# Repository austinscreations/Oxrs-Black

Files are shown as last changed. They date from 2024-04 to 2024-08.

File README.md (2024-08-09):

# Oxrs-Black
a custom rack controller that is based of the rack32 but includes some upgrades and major changes

With the latest update on 2024-08-09
- known part qty missing for the optoisolators - these are needed for KNX function. 

you can leave them off or preorder the part before PCBa from JLC
- https://jlcpcb.com/partdetail/avago_broadcom-ACPL_M61L500E/C44908

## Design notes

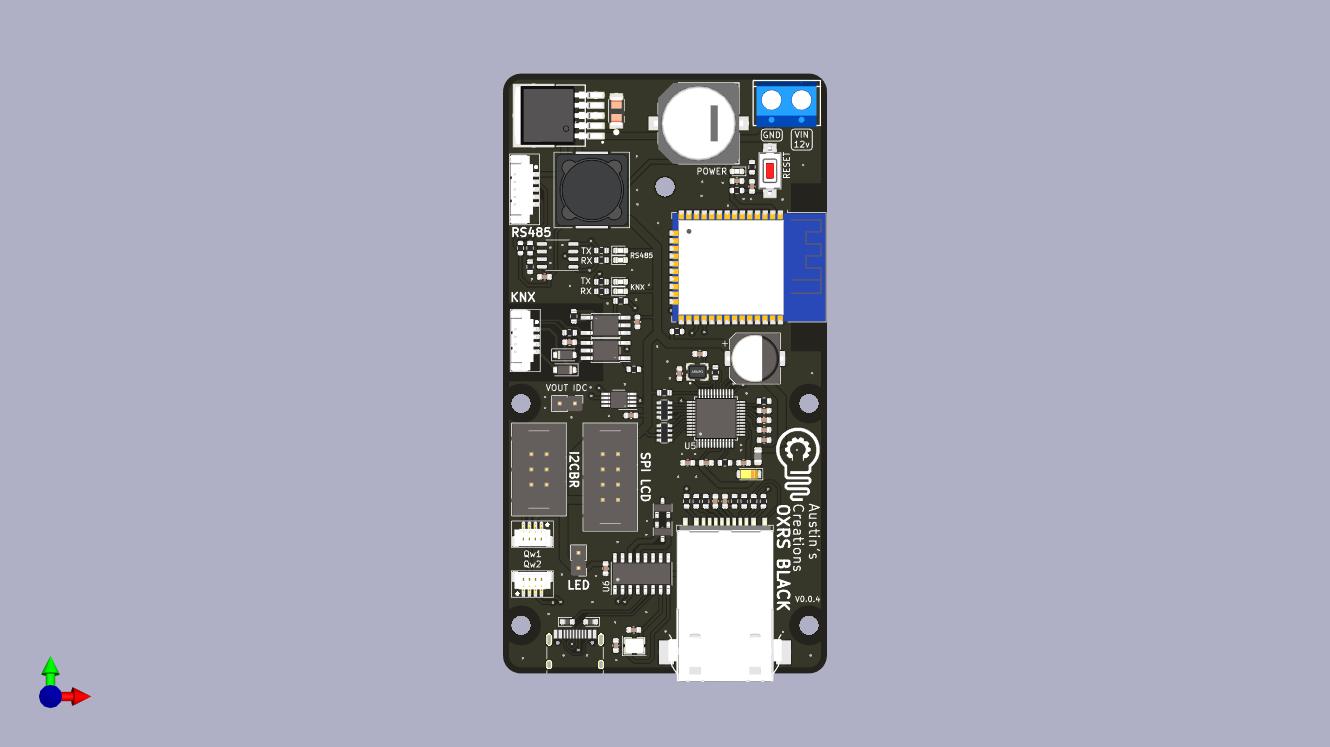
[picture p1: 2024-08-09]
rev 4/oxrs black 004 front.jpg

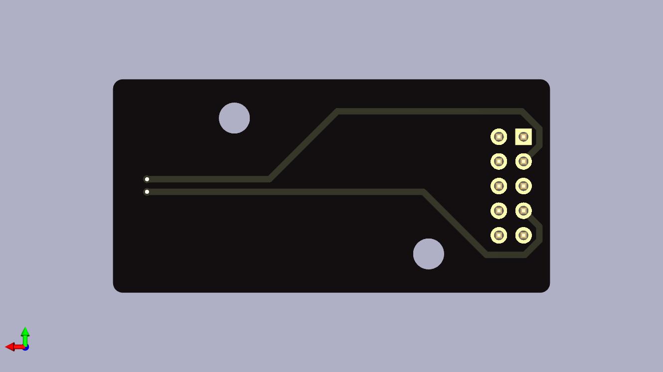
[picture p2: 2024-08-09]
knx adapter/knx adapter bottom.jpg

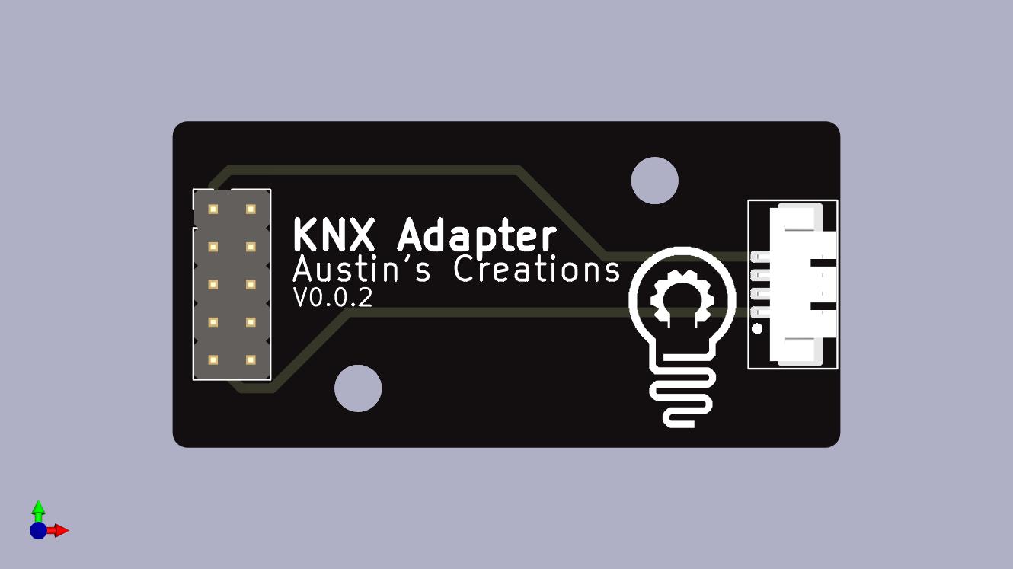
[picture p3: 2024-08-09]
knx adapter/knx adapter top.jpg

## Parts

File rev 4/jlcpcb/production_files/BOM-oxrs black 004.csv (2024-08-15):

Comment | Designator | Footprint | LCSC
PGB1010603NR | D7,D8 | D_0603_1608Metric | C10677
10uF 6.3V A TANT | C12 | CP_EIA-3216-18_Kemet-A | C127946
CH340G | U6 | SOIC-16_3.9x9.9mm_P1.27mm | C14267
qwiic_vertical | Qw1,Qw2 | qwiic vertical | C145961
100nF | C10,C15,C17,C18,C21,C3,C4,C5,C6 | C_0603_1608Metric | C14663
1uF | C9 | C_0603_1608Metric | C15849
20pF | C22,C23,C7,C8 | C_0603_1608Metric | C1648
4.7uF | C16 | C_0603_1608Metric | C19666
10uF | C11 | C_0603_1608Metric | C19702
MMBT3904 | Q1,Q2 | SOT-23 | C20526
22nF | C20 | C_0603_1608Metric | C21122
1k | R2,R3,R4,R5,R6,R7,R8,R9 | R_0603_1608Metric | C21190
KNX | J7 | 4 pin jst 1.25 vertical | C225106
RS485 | J4 | 5 pin jst 1.25 vertical | C225107
120R | R12 | R_0603_1608Metric | C22787
10R | R23 | R_0603_1608Metric | C22859
red | D2,D4,D6 | LED_0603_1608Metric | C2286
1M | R13 | R_0603_1608Metric | C22935
470R | R24,R25 | R_0603_1608Metric | C23179
49.9R | R19,R20,R21,R22 | R_0603_1608Metric | C23185
10k | R1,R10,R11,R14,R15,R16,R17 | R_0603_1608Metric | C25804
25MHz_SMD_Crystal_Resonator | Y1 | 25MHz_SMD_Crystal_Resonator | C258949
USB_C_Receptacle_USB2.0 | J6 | USB_C_Receptacle_HRO_TYPE-C-31-M-12 | C2765186
10k | RN1,RN2 | R_Array_Convex_4x0603 | C29718
ESP32-WROOM-32E | U4 | ESP32-WROOM-32 | C3013935
12.4k | R18 | R_0603_1608Metric | C310267
W5500 | U5 | LQFP-48_7x7mm_P0.5mm | C32843
LM2596S-3V3 | PS1 | LM2596S | C347420
2pinblock | TB1 | 2pinblock | C395885
button | B1 | button | C410373
ACPL-M61L-500E | U2,U3 | SO-5_4.4x3.6mm_P1.27mm | C44908
Conn_01x02 | J1,J3 | PinHeader_1x02_P2.54mm_Vertical | C492401
220uF 35v | C2 | CP_Elec_8x6.2 | C5162357
HR961160C | RJ45_1 | HR961160C | C55683
10nF | C13,C14,C19 | C_0603_1608Metric | C57112
CONN_03X2SHROUD | IDC1 | IDC-Header_2x03_P2.54mm_Vertical | C601936
SPI-LCD | J2 | IDC-Header_2x04_P2.54mm_Vertical | C601937
SM4007 | D10,D9 | D_SOD-123F | C64898
MAX3485 | U1 | SOP-8_3.9x4.9mm_P1.27mm | C668204
yellow | D3,D5 | LED_0603_1608Metric | C72038
TCA4307 | IC1 | VSSOP-8_3.0x3.0mm_P0.65mm | C880333
Crystal_GND23 | Y2 | Crystal_SMD_3225-4Pin_3.2x2.5mm | C9002
33uH | L1 | 12x12x8 inductor | C9400
PMEG4050EP | D1 | PMEG3050EP | C96235
680uF 35v | C1 | large capacitor 12.5d 13.5h | C98216
1uH 250mA 0805 | L2 | L_0805_2012Metric | C98325

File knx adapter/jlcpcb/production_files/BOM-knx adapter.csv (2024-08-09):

Comment | Designator | Footprint | LCSC
Conn_02x05_Odd_Even | J1 | PinHeader_2x05_P2.54mm_Vertical | C115170
KNX | J2 | 4 pin jst 1.25 horizontal | C225113

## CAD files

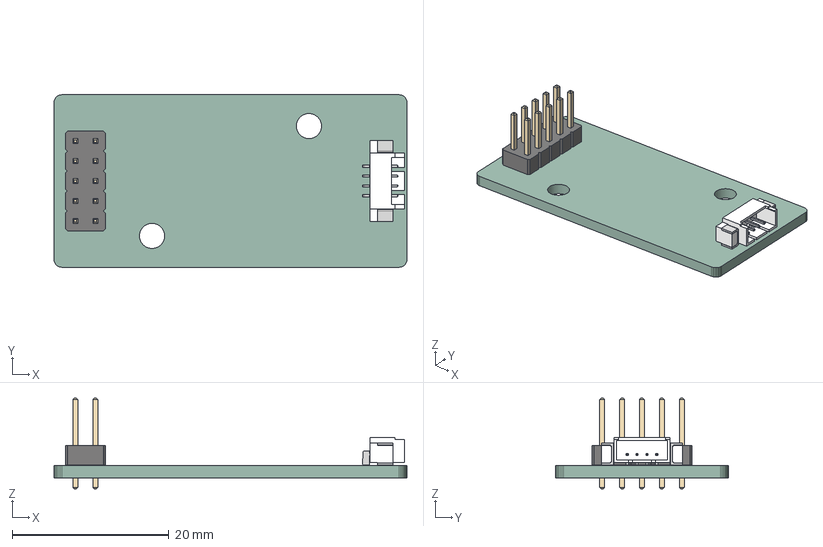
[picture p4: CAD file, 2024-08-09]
knx adapter/knx adapter.step
45.0 x 22.0 x 11.5 mm
knx adapter PCB

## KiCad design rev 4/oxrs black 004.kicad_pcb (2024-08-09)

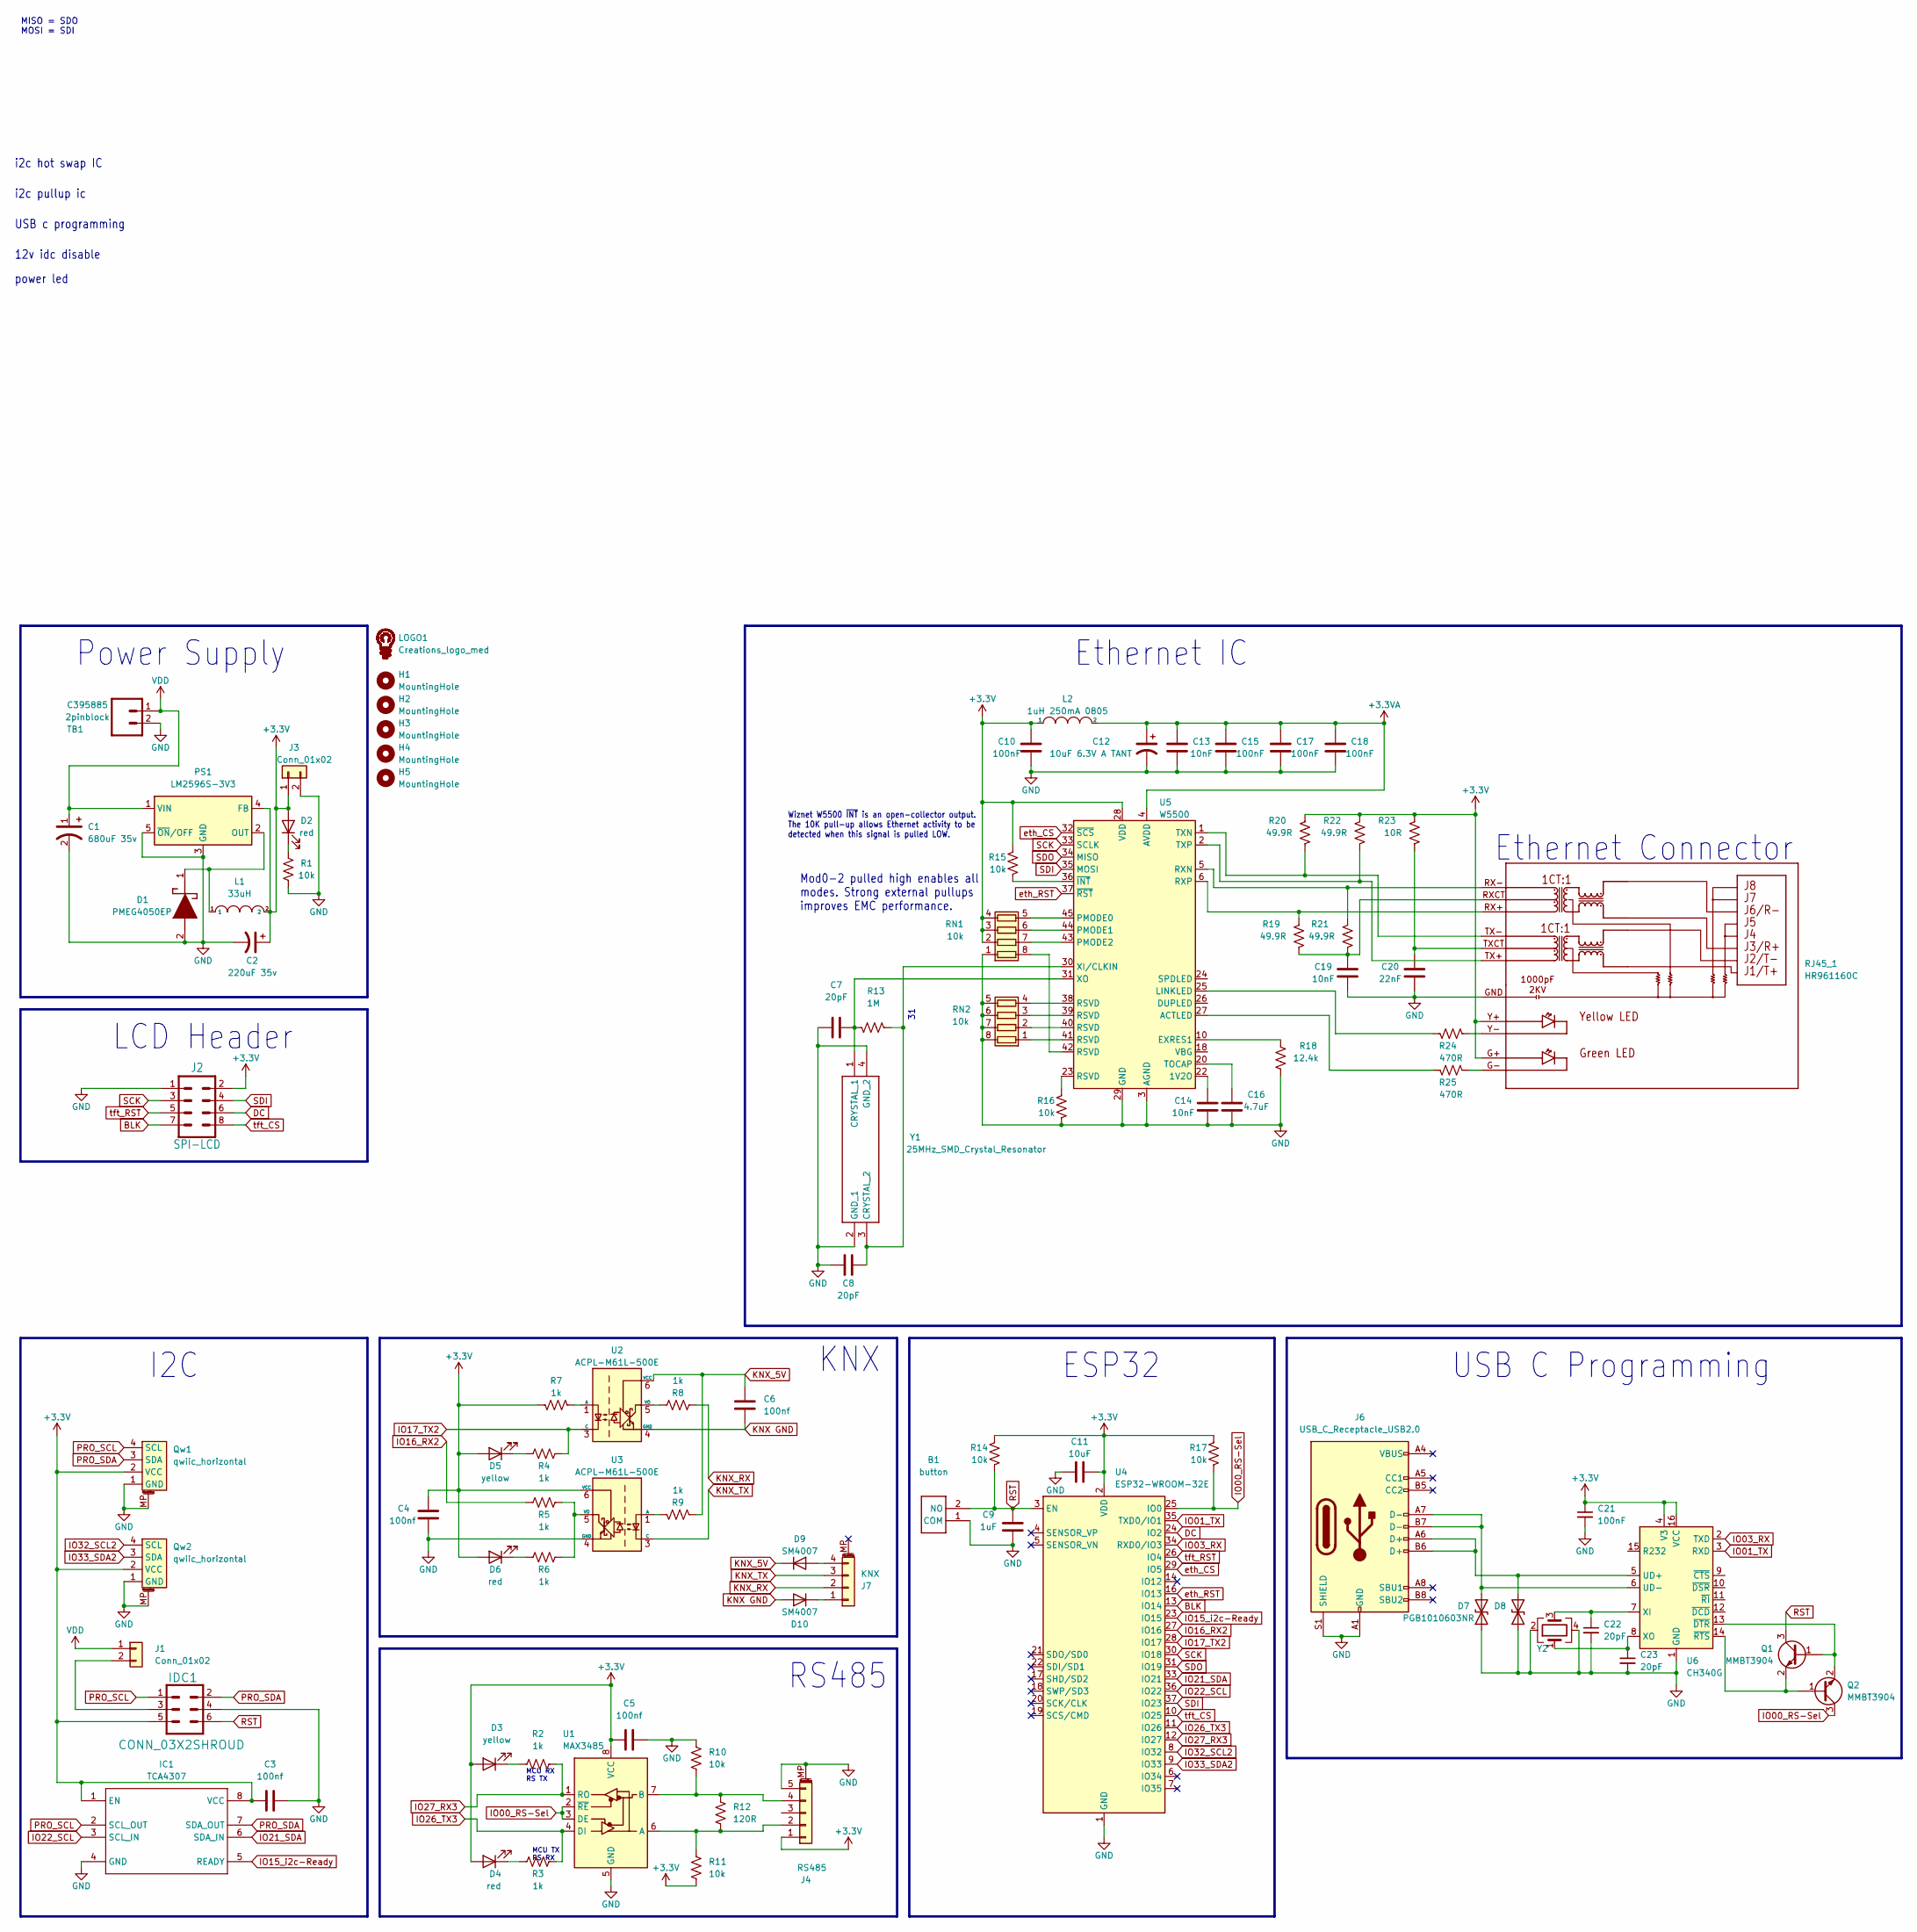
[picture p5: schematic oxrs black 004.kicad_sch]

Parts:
B1: button; LCSC C410373
C1: 680uF 35v; large capacitor 12.5d 13.5h; LCSC C98216
C2: 220uF 35v; CP_Elec_8x6.2; LCSC C5162357
C3, C4, C5, C6: 100nf; C_0603_1608Metric; LCSC C14663
C7, C8, C22, C23: 20pF; C_0603_1608Metric; LCSC C1648
C9: 1uF; C_0603_1608Metric; LCSC C15849
C10, C15, C17, C18, C21: 100nF; C_0603_1608Metric; LCSC C14663
C11: 10uF; C_0603_1608Metric; LCSC C19702
C12: 10uF 6.3V A TANT; CP_EIA-3216-18_Kemet-A; LCSC C127946
C13, C14, C19: 10nF; C_0603_1608Metric; LCSC C57112
C16: 4.7uF; C_0603_1608Metric; LCSC C19666
C20: 22nF; C_0603_1608Metric; LCSC C21122
D1: PMEG4050EP; PMEG3050EP; LCSC C96235
D2, D4, D6: red; LED_0603_1608Metric; LCSC C2286
D3, D5: yellow; LED_0603_1608Metric; LCSC C72038
D7, D8: PGB1010603NR; D_0603_1608Metric; LCSC C10677
D9, D10: SM4007; D_SOD-123F; LCSC C64898
H1, H2, H3, H4, H5: MountingHole; MountingHole_3.2mm_M3
IC1: TCA4307; VSSOP-8_3.0x3.0mm_P0.65mm; LCSC C880333
IDC1: CONN_03X2SHROUD; IDC-Header_2x03_P2.54mm_Vertical; LCSC C601936
J1, J3: Conn_01x02; PinHeader_1x02_P2.54mm_Vertical; LCSC C492401
J2: SPI-LCD; IDC-Header_2x04_P2.54mm_Vertical; LCSC C601937
J4: RS485; 5 pin jst 1.25 vertical; LCSC C225107
J6: USB_C_Receptacle_USB2.0; USB_C_Receptacle_HRO_TYPE-C-31-M-12; LCSC C2765186
J7: KNX; 4 pin jst 1.25 vertical; LCSC C225106
L1: 33uH; 12x12x8 inductor; LCSC C9400
L2: 1uH 250mA 0805; L_0805_2012Metric; LCSC C98325
LOGO1: Creations_logo_med; Creations logo med
PS1: LM2596S-3V3; LM2596S; LCSC C347420
Q1, Q2: MMBT3904; SOT-23; LCSC C20526
Qw1, Qw2: qwiic_horizontal; qwiic vertical; part # C145961; LCSC C145956
R1, R10, R11, R14, R15, R16, R17: 10k; R_0603_1608Metric; LCSC C25804
R2, R3, R4, R5, R6, R7, R8, R9: 1k; R_0603_1608Metric; LCSC C21190
R12: 120R; R_0603_1608Metric; LCSC C22787
R13: 1M; R_0603_1608Metric; LCSC C22935
R18: 12.4k; R_0603_1608Metric; LCSC C310267
R19, R20, R21, R22: 49.9R; R_0603_1608Metric; LCSC C23185
R23: 10R; R_0603_1608Metric; LCSC C22859
R24, R25: 470R; R_0603_1608Metric; LCSC C23179
RJ45_1: HR961160C; LCSC C55683
RN1, RN2: 10k; R_Array_Convex_4x0603; LCSC C29718
TB1: 2pinblock; LCSC C395885
U1: MAX3485; SOP-8_3.9x4.9mm_P1.27mm; part # C9943; LCSC C668204
U2, U3: ACPL-M61L-500E; SO-5_4.4x3.6mm_P1.27mm; LCSC C44908
U4: ESP32-WROOM-32E; ESP32-WROOM-32; LCSC C3013935
U5: W5500; LQFP-48_7x7mm_P0.5mm; LCSC C32843
U6: CH340G; SOIC-16_3.9x9.9mm_P1.27mm; LCSC C14267
Y1: 25MHz_SMD_Crystal_Resonator; LCSC C258949
Y2: Crystal_GND23; Crystal_SMD_3225-4Pin_3.2x2.5mm; LCSC C9002

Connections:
+3.3VA: C12.1, C13.2, C15.2, C17.2, C18.2, L2.2, U5.4 (AVDD), U5.8 (AVDD), U5.11 (AVDD), U5.15 (AVDD), U5.17 (AVDD), U5.21 (AVDD)
+3V3: C2.1, C3.2, C4.1, C5.2, C10.2, C11.2, C21.1, D2.2 (A), D3.2 (A), D4.2 (A), D5.2 (A), D6.2 (A), IC1.1 (EN), IC1.8 (VCC), IDC1.5, J2.2, J3.1, J4.1, L1.2, L2.1, PS1.4 (FB), Qw1.2 (VCC), Qw2.2 (VCC), R7.1, R11.1, R14.2, R15.2, R17.2, R20.2, R22.2, R23.2, RJ45_1.G+, RJ45_1.Y+, RN1.2 (R2.1), RN1.3 (R3.1), RN1.4 (R4.1), U1.8 (VCC), U3.6 (VCC), U4.2 (VDD), U5.28 (VDD), U6.4 (V3), U6.16 (VCC)
BLK: J2.7, U4.13 (IO14)
DC: J2.6, U4.24 (IO2)
GND: B1.1 (COM), C1.2, C2.2, C3.1, C4.2, C5.1, C7.1, C8.1, C9.1, C10.1, C11.1, C12.2, C13.1, C14.1, C15.1, C16.1, C17.1, C18.1, C19.1, C20.1, C21.2, C22.2, C23.2, D1.2 (A), D7.1 (A1), D8.1 (A1), IC1.4 (GND), IDC1.4, J2.1, J3.2, J4.5, J4.MP (MountPin), J6.A1 (GND), J6.A12 (GND), J6.B1 (GND), J6.B12 (GND), J6.S1 (SHIELD), PS1.3 (GND), PS1.5 (~ON/OFF), Qw1.1 (GND), Qw1.MP, Qw2.1 (GND), Qw2.MP, R1.2, R10.2, R16.1, R18.1, RJ45_1.GND (GNDF), RN1.1 (R1.1), RN2.5 (R4.2), RN2.6 (R3.2), RN2.7 (R2.2), RN2.8 (R1.2), TB1.2, U1.5 (GND), U3.4 (GND), U4.1 (GND), U4.15 (GND), U4.38 (GND), U4.39 (GND), U5.3 (AGND), U5.9 (AGND), U5.14 (AGND), U5.16 (AGND), U5.19 (AGND), U5.29 (GND), U5.48 (AGND), U6.1 (GND), Y1.2 (GND_1), Y1.4 (GND_2), Y2.2, Y2.4
IO00_RS-Sel: Q2.3 (C), R17.1, U1.2 (~RE), U1.3 (DE), U4.25 (IO0)
IO01_TX: U4.35 (TXD0/IO1), U6.3 (RXD)
IO03_RX: U4.34 (RXD0/IO3), U6.2 (TXD)
IO15_i2c-Ready: IC1.5 (READY), U4.23 (IO15)
IO16_RX2: R5.1, U4.27 (IO16)
IO17_TX2: R4.2, U2.3 (C), U4.28 (IO17)
IO21_SDA: IC1.6 (SDA_IN), U4.33 (IO21)
IO22_SCL: IC1.3 (SCL_IN), U4.36 (IO22)
IO26_TX3: R3.2, U1.4 (DI), U4.11 (IO26)
IO27_RX3: R2.2, U1.1 (RO), U4.12 (IO27)
IO32_SCL2: Qw2.4 (SCL), U4.8 (IO32)
IO33_SDA2: Qw2.3 (SDA), U4.9 (IO33)
KNX GND: C6.2, D10.2 (A), U2.4 (GND)
KNX_5V: C6.1, D9.1 (K), R9.2, U2.6 (VCC)
KNX_RX: J7.2, R8.1
KNX_TX: J7.3, U3.3 (C)
unnamed: C19.2, R19.1, R21.1, RJ45_1.RXCT
unnamed: C20.2, R23.1, RJ45_1.TXCT
unnamed: D1.1 (K), L1.1, PS1.2 (OUT)
unnamed: D2.1 (K), R1.1
unnamed: D3.1 (K), R2.1
unnamed: D4.1 (K), R3.1
unnamed: D5.1 (K), R4.1
unnamed: D6.1 (K), R6.1
unnamed: D7.2 (A2), J6.A7 (D-), J6.B7 (D-), U6.6 (UD-)
unnamed: D8.2 (A2), J6.A6 (D+), J6.B6 (D+), U6.5 (UD+)
unnamed: D9.2 (A), J7.4
unnamed: D10.1 (K), J7.1
unnamed: IDC1.3, J1.2
unnamed: J4.2, R11.2, R12.1, U1.6 (A)
unnamed: J4.4, R10.1, R12.2, U1.7 (B)
unnamed: Q1.1 (B), Q2.2 (E), U6.13 (~DTR)
unnamed: Q1.2 (E), Q2.1 (B), U6.14 (~RTS)
unnamed: R16.2, U5.23 (RSVD)
unnamed: R24.1, RJ45_1.Y-
unnamed: R25.1, RJ45_1.G-
unnamed: RN1.8 (R1.2), U5.42 (RSVD)
unnamed: RN1.7 (R2.2), U5.43 (PMODE2)
unnamed: RN1.6 (R3.2), U5.44 (PMODE1)
unnamed: RN1.5 (R4.2), U5.45 (PMODE0)
unnamed: RN2.1 (R1.1), U5.41 (RSVD)
unnamed: RN2.2 (R2.1), U5.40 (RSVD)
unnamed: RN2.3 (R3.1), U5.39 (RSVD)
unnamed: RN2.4 (R4.1), U5.38 (RSVD)
unnamed: R7.2, U2.1 (A)
unnamed: R8.2, U2.5 (VO)
unnamed: R9.1, U3.1 (A)
unnamed: R5.2, R6.2, U3.5 (VO)
unnamed: C14.2, U5.22 (1V2O)
unnamed: R25.2, U5.27 (ACTLED)
unnamed: R18.2, U5.10 (EXRES1)
unnamed: R24.2, U5.25 (LINKLED)
unnamed: R21.2, RJ45_1.RX-, U5.5 (RXN)
unnamed: R19.2, RJ45_1.RX+, U5.6 (RXP)
unnamed: C16.2, U5.20 (TOCAP)
unnamed: R20.1, RJ45_1.TX-, U5.1 (TXN)
unnamed: R22.1, RJ45_1.TX+, U5.2 (TXP)
unnamed: C8.2, R13.2, U5.30 (XI/CLKIN), Y1.3 (CRYSTAL_2)
unnamed: C7.2, R13.1, U5.31 (XO), Y1.1 (CRYSTAL_1)
unnamed: R15.1, U5.36 (~INT)
unnamed: C22.1, U6.7 (XI), Y2.3
unnamed: C23.1, U6.8 (XO), Y2.1
PRO_SCL: IC1.2 (SCL_OUT), IDC1.1, Qw1.4 (SCL)
PRO_SDA: IC1.7 (SDA_OUT), IDC1.2, Qw1.3 (SDA)
RST: B1.2 (NO), C9.2, IDC1.6, Q1.3 (C), R14.1, U4.3 (EN)
SCK: J2.3, U4.30 (IO18), U5.33 (SCLK)
SDI: J2.4, U4.37 (IO23), U5.35 (MOSI)
SDO: U4.31 (IO19), U5.34 (MISO)
VDD: C1.1, J1.1, PS1.1 (VIN), TB1.1
eth_CS: U4.29 (IO5), U5.32 (~SCS)
eth_RST: U4.16 (IO13), U5.37 (~RST)
tft_CS: J2.8, U4.10 (IO25)
tft_RST: J2.5, U4.26 (IO4)

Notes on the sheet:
I2C
Power Supply
power led
ESP32
Mod0-2 pulled high enables all modes. Strong external pullups improves EMC performance.
LCD Header
KNX
MISO = SDO MOSI = SDI
i2c hot swap IC
i2c pullup ic
Ethernet Connector
USB C Programming
MCU RX RS TX
Ethernet IC
12v idc disable
RS485
MCU TX RS RX
USB c programming
Wiznet W5500 ~{INT} is an open-collector output. The 10K pull-up allows Ethernet activity to be detected when this signal is pulled LOW.

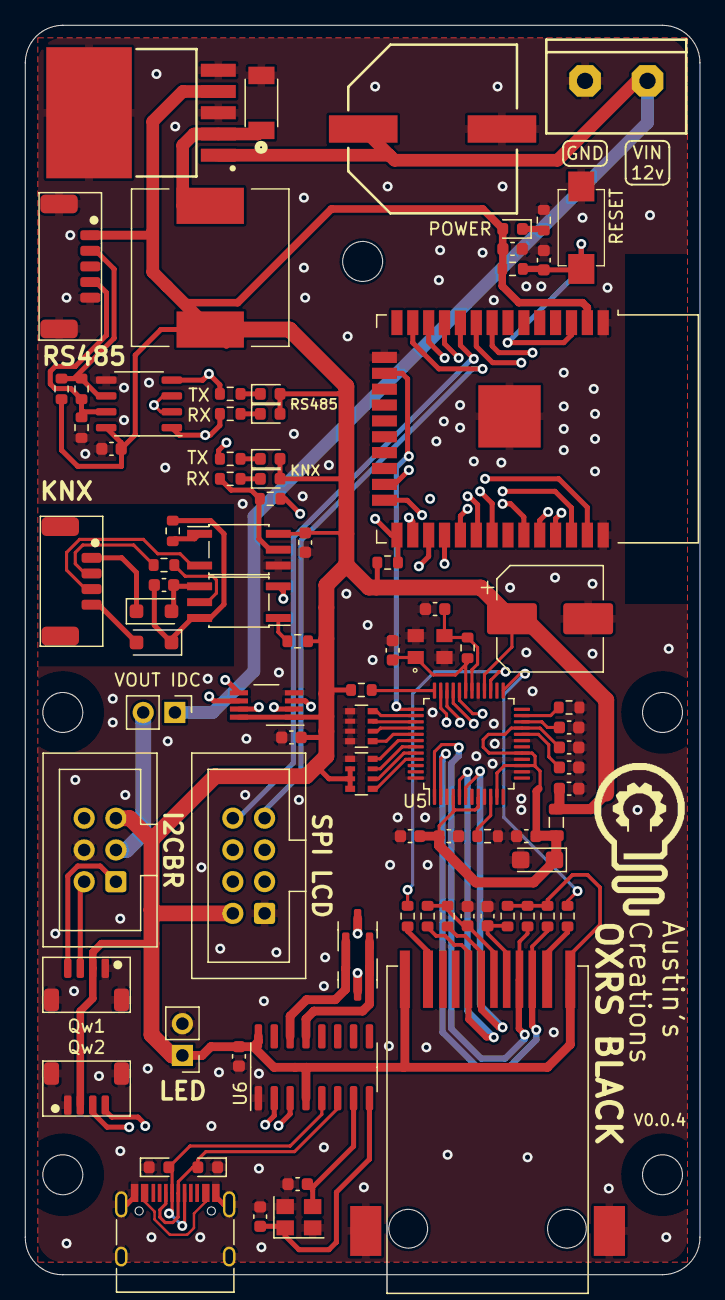
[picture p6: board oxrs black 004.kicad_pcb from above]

Board: 4 copper layers, 54.0 x 100.0 mm, 92 parts (0 on the bottom side), 78 nets.

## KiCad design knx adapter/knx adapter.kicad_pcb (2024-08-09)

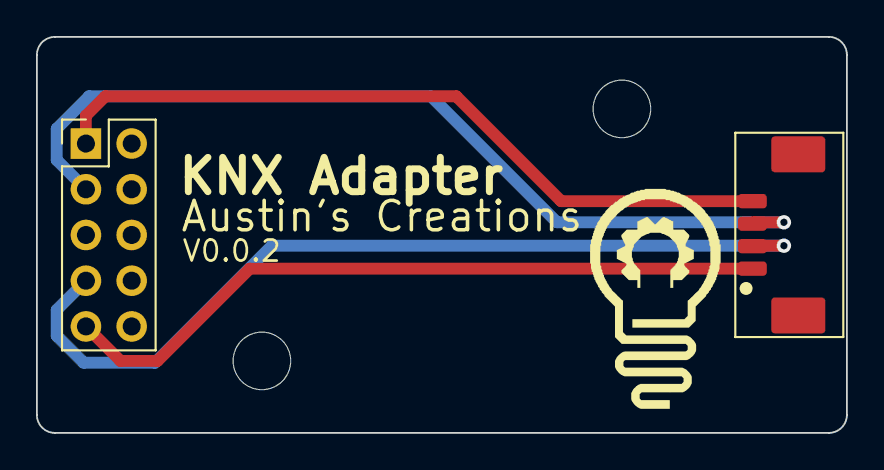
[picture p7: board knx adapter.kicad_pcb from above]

Board: 2 copper layers, 45.0 x 22.0 mm, 5 parts (0 on the bottom side), 4 nets.

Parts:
H1, H2: MountingHole; MountingHole_3.2mm_M3
J1: Conn_02x05_Odd_Even; PinHeader_2x05_P2.54mm_Vertical
J2: KNX; 4 pin jst 1.25 horizontal
LOGO1: Creations_logo_med; Creations logo med

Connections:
KNX GND: J1.9, J2.1
KNX_5V: J1.1, J2.4
KNX_RX: J1.7, J2.2
KNX_TX: J1.3, J2.3

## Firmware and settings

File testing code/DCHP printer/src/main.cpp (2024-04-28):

#include <Arduino.h>
#include <WiFi.h> 
#include <SPI.h>
#include <Ethernet.h>
#include <OXRS_MQTT.h>                // For MQTT
#include <OXRS_API.h>                 // For REST API
#include <LittleFS.h>
// #include <EthernetSPI2.h>

/*--------------------------- Version ------------------------------------*/
#define FW_NAME       "OXRS-AC-ETH_TEST-ESP32-FW"
#define FW_SHORT_NAME "ETH TEST"
#define FW_MAKER      "Austin's Creations"
#define FW_VERSION    "0.0.1"


// #define       ETH_SCLK                  32
// #define       ETH_MISO                  27
// #define       ETH_MOSI                  33
// #define       ETHERNET_CS_PIN           26
// #define       WIZNET_RST_PIN            25
#define       DHCP_TIMEOUT_MS           15000
#define       DHCP_RESPONSE_TIMEOUT_MS  4000

#define       DISPLAY_CS_PIN            15

// Serial
#define       SERIAL_BAUD_RATE          115200

// REST API
#define       REST_API_PORT             80

// stack size counter (for determine used heap size on ESP8266)
char * g_stack_start;

// client && server
EthernetClient client;
EthernetServer server(REST_API_PORT);

// MQTT
PubSubClient mqttClient(client);
OXRS_MQTT mqtt(mqttClient);

// REST API
OXRS_API api(mqtt);

#if defined(api_new)
/*--------------------------- JSON builders -----------------*/
uint32_t getStackSize()
{
  char stack;
  return (uint32_t)g_stack_start - (uint32_t)&stack;  
}

void getFirmwareJson(JsonVariant json)
{
  JsonObject firmware = json.createNestedObject("firmware");

  firmware["name"] = FW_NAME;
  firmware["shortName"] = FW_SHORT_NAME;
  firmware["maker"] = FW_MAKER;
  firmware["version"] = FW_VERSION;

#if defined(FW_GITHUB_URL)
  firmware["githubUrl"] = FW_GITHUB_URL;
#endif
}
void getSystemJson(JsonVariant json)
{
  JsonObject system = json.createNestedObject("system");

  system["flashChipSizeBytes"] = ESP.getFlashChipSize();
  system["heapFreeBytes"] = ESP.getFreeHeap();

  system["heapUsedBytes"] = ESP.getHeapSize();
  system["heapMaxAllocBytes"] = ESP.getMaxAllocHeap();

  system["sketchSpaceUsedBytes"] = ESP.getSketchSize();
  system["sketchSpaceTotalBytes"] = ESP.getFreeSketchSpace();

  system["fileSystemUsedBytes"] = LittleFS.usedBytes();
  system["fileSystemTotalBytes"] = LittleFS.totalBytes();

}

void getNetworkJson(JsonVariant json)
{
  JsonObject network = json.createNestedObject("network");
  
  byte mac[6];
  
  network["mode"] = "ethernet";
  Ethernet.MACAddress(mac);
  network["ip"] = Ethernet.localIP();
  
  char mac_display[18];
  sprintf_P(mac_display, PSTR("%02X:%02X:%02X:%02X:%02X:%02X"), mac[0], mac[1], mac[2], mac[3], mac[4], mac[5]);
  network["mac"] = mac_display;
}

void getConfigSchemaJson(JsonVariant json)
{
  JsonObject configSchema = json.createNestedObject("configSchema");
  
  // Config schema metadata
  configSchema["$schema"] = JSON_SCHEMA_VERSION;
  configSchema["title"] = FW_SHORT_NAME;
  configSchema["type"] = "object";

  JsonObject properties = configSchema.createNestedObject("properties");

}

void getCommandSchemaJson(JsonVariant json)
{
  JsonObject commandSchema = json.createNestedObject("commandSchema");
  
  // Command schema metadata
  commandSchema["$schema"] = JSON_SCHEMA_VERSION;
  commandSchema["title"] = FW_SHORT_NAME;
  commandSchema["type"] = "object";

  JsonObject properties = commandSchema.createNestedObject("properties");

  JsonObject restart = properties.createNestedObject("restart");
  restart["type"] = "boolean";
  restart["description"] = "Restart the controller";
}

void apiAdopt(JsonVariant json)
{
  // Build device adoption info
  getFirmwareJson(json);
  getSystemJson(json);
  getNetworkJson(json);
  getConfigSchemaJson(json);
  getCommandSchemaJson(json);
}

/*--------------------------- Initialisation -------------------------------*/
void initialiseRestApi(void)
{
  // NOTE: this must be called *after* initialising MQTT since that sets
  //       the default client id, which has lower precendence than MQTT
  //       settings stored in file and loaded by the API

  // Set up the REST API
  api.begin();

  // Register our callbacks
  api.onAdopt(apiAdopt);

  server.begin();
}

/*--------------------------- MQTT/API -----------------*/
void mqttConnected() 
{
  // Publish device adoption info
  DynamicJsonDocument json(JSON_ADOPT_MAX_SIZE);
  mqtt.publishAdopt(api.getAdopt(json.as<JsonVariant>()));

  // Log the fact we are now connected
  Serial.println("[TEST] mqtt connected");
}

void mqttDisconnected(int state) 
{
  // Log the disconnect reason
  // See https://github.com/knolleary/pubsubclient/blob/2d228f2f862a95846c65a8518c79f48dfc8f188c/src/PubSubClient.h#L44
  switch (state)
  {
    case MQTT_CONNECTION_TIMEOUT:
      Serial.println(F("[TEST] mqtt connection timeout"));
      break;
    case MQTT_CONNECTION_LOST:
      Serial.println(F("[TEST] mqtt connection lost"));
      break;
    case MQTT_CONNECT_FAILED:
      Serial.println(F("[TEST] mqtt connect failed"));
      break;
    case MQTT_DISCONNECTED:
      Serial.println(F("[TEST] mqtt disconnected"));
      break;
    case MQTT_CONNECT_BAD_PROTOCOL:
      Serial.println(F("[TEST] mqtt bad protocol"));
      break;
    case MQTT_CONNECT_BAD_CLIENT_ID:
      Serial.println(F("[TEST] mqtt bad client id"));
      break;
    case MQTT_CONNECT_UNAVAILABLE:
      Serial.println(F("[TEST] mqtt unavailable"));
      break;
    case MQTT_CONNECT_BAD_CREDENTIALS:
      Serial.println(F("[TEST] mqtt bad credentials"));
      break;      
    case MQTT_CONNECT_UNAUTHORIZED:
      Serial.println(F("[TEST] mqtt unauthorised"));
      break;      
  }
}

void jsonCommand(JsonVariant json)
{
  if (json.containsKey("restart") && json["restart"].as<bool>())
  {
    ESP.restart();
  }
}

void jsonConfig(JsonVariant json)
{
  
}

void mqttCallback(char * topic, uint8_t * payload, unsigned int length) 
{
  // Pass this message down to our MQTT handler
  mqtt.receive(topic, payload, length);
}

void initialiseMqtt(byte * mac)
{
  // Set the default client id to the last 3 bytes of the MAC address
  char clientId[32];
  sprintf_P(clientId, PSTR("%02x%02x%02x"), mac[3], mac[4], mac[5]);  
  mqtt.setClientId(clientId);
  
  // Register our callbacks
  mqtt.onConnected(mqttConnected);
  mqtt.onDisconnected(mqttDisconnected);
  mqtt.onConfig(jsonConfig);
  mqtt.onCommand(jsonCommand);  

  // Start listening for MQTT messages
  mqttClient.setCallback(mqttCallback);  
}

/*--------------------------- Network -------------------------------*/
void initialiseEthernet()
{
  // Get ESP base MAC address
  byte mac[6];
  WiFi.macAddress(mac);
  
  // Ethernet MAC address is base MAC + 3
  // See https://docs.espressif.com/projects/esp-idf/en/latest/esp32/api-reference/system/system.html#mac-address
  mac[5] += 3;

  // Display the MAC address on serial
  char mac_display[18];
  sprintf_P(mac_display, PSTR("%02X:%02X:%02X:%02X:%02X:%02X"), mac[0], mac[1], mac[2], mac[3], mac[4], mac[5]);
  Serial.print(F("[TEST] mac address: "));
  Serial.println(mac_display);

  // Initialise ethernet library
  Ethernet.init(ETHERNET_CS_PIN);

  // Reset Wiznet W5500
  pinMode(WIZNET_RST_PIN, OUTPUT);
  digitalWrite(WIZNET_RST_PIN, HIGH);
  delay(250);
  digitalWrite(WIZNET_RST_PIN, LOW);
  delay(50);
  digitalWrite(WIZNET_RST_PIN, HIGH);
  delay(350);

  // Get an IP address via DHCP
  Serial.print(F("[TEST] ip address: "));

  // SPI.begin(ETH_SCLK, ETH_MISO, ETH_MOSI, ETHERNET_CS_PIN);

  if (!Ethernet.begin(mac, DHCP_TIMEOUT_MS, DHCP_RESPONSE_TIMEOUT_MS))
  {
    if (Ethernet.hardwareStatus() == EthernetNoHardware) {
      Serial.println(F("ethernet shield not found"));
    } else if (Ethernet.linkStatus() == LinkOFF) {
      Serial.println(F("ethernet cable not connected"));
    } else {
      Serial.println(F("failed to setup ethernet using DHCP"));
    }
    return;
  }
  
  // Display IP address on serial
  Serial.println(Ethernet.localIP());

  // Set up MQTT (don't attempt to connect yet)
  initialiseMqtt(mac);

  // Set up the REST API once we have an IP address
  initialiseRestApi();

}

void initialiseSerial()
{
  Serial.begin(SERIAL_BAUD_RATE);
  delay(1000);
  
  Serial.println(F("[TEST ] starting up..."));

  DynamicJsonDocument json(128);
  getFirmwareJson(json.as<JsonVariant>());

  Serial.print(F("[TEST ] "));
  serializeJson(json, Serial);
  Serial.println();
}
#endif

#if defined(api_old)
void initialiseEthernet(byte * mac)
{
  // Get ESP32 base MAC address
  WiFi.macAddress(mac);
  
  // Ethernet MAC address is base MAC + 3
  // See https://docs.espressif.com/projects/esp-idf/en/latest/esp32/api-reference/system/system.html#mac-address
  mac[5] += 3;

  // Display the MAC address on serial
  char mac_display[18];
  sprintf_P(mac_display, PSTR("%02X:%02X:%02X:%02X:%02X:%02X"), mac[0], mac[1], mac[2], mac[3], mac[4], mac[5]);
  Serial.print(F(" mac address: "));
  Serial.println(mac_display);

  // Initialise ethernet library
  Ethernet.init(ETHERNET_CS_PIN);

  // Reset Wiznet W5500
  pinMode(WIZNET_RST_PIN, OUTPUT);
  digitalWrite(WIZNET_RST_PIN, HIGH);
  delay(250);
  digitalWrite(WIZNET_RST_PIN, LOW);
  delay(50);
  digitalWrite(WIZNET_RST_PIN, HIGH);
  delay(350);

  // Get an IP address via DHCP and display on serial
  Serial.print(F("ip address: "));
  SPI.begin(ETH_SCLK, ETH_MISO, ETH_MOSI, ETHERNET_CS_PIN);
  if (Ethernet.begin(mac, DHCP_TIMEOUT_MS, DHCP_RESPONSE_TIMEOUT_MS))
  {
    Serial.println(Ethernet.localIP());
  }
  else
  {
    Serial.println("Failed to configure Ethernet using DHCP");
    if (Ethernet.hardwareStatus() == EthernetNoHardware) {
      Serial.println("Ethernet shield was not found.  Sorry, can't run without hardware. :(");
    } else if (Ethernet.linkStatus() == LinkOFF) {
      Serial.println("Ethernet cable is not connected.");
    }
  }
}

/**
  MQTT
*/
void mqttCallback(char * topic, uint8_t * payload, unsigned int length) 
{
  // Pass this message down to our MQTT handler
  mqtt.receive(topic, payload, length);
}


void getFirmwareJson(JsonVariant json)
{
  JsonObject firmware = json.createNestedObject("firmware");

  firmware["name"] = FW_NAME;
  firmware["shortName"] = FW_SHORT_NAME;
  firmware["maker"] = FW_MAKER;
  firmware["version"] = FW_VERSION;
}

void getNetworkJson(JsonVariant json)
{
  byte mac[6];
  WiFi.macAddress(mac);
  
  char mac_display[18];
  sprintf_P(mac_display, PSTR("%02X:%02X:%02X:%02X:%02X:%02X"), mac[0], mac[1], mac[2], mac[3], mac[4], mac[5]);

  JsonObject network = json.createNestedObject("network");


  network["ip"] = Ethernet.localIP();

  network["mac"] = mac_display;
}

void getConfigSchemaJson(JsonVariant json)
{
  JsonObject configSchema = json.createNestedObject("configSchema");
  
  // Config schema metadata
  configSchema["$schema"] = "http://json-schema.org/draft-07/schema#";
  configSchema["title"] = FW_NAME;
  configSchema["type"] = "object";



}

void getCommandSchemaJson(JsonVariant json)
{
  JsonObject commandSchema = json.createNestedObject("commandSchema");
  
  // Command schema metadata
  commandSchema["$schema"] = "http://json-schema.org/draft-07/schema#";
  commandSchema["title"] = FW_NAME;
  commandSchema["type"] = "object";


}


/**
  API callbacks
*/
void apiAdopt(JsonVariant json)
{
  // Build device adoption info
  getFirmwareJson(json);
  getNetworkJson(json);
  getConfigSchemaJson(json);
  getCommandSchemaJson(json);
}

/**
  MQTT callbacks
*/
void mqttConnected() 
{
  // Build device adoption info
  // Build device adoption info
  DynamicJsonDocument json(JSON_ADOPT_MAX_SIZE);
  mqtt.publishAdopt(api.getAdopt(json.as<JsonVariant>()));

  // Log the fact we are now connected
  Serial.println("[TLC] mqtt connected");
}

void mqttDisconnected(int state) 
{
  // Log the disconnect reason
  // See https://github.com/knolleary/pubsubclient/blob/2d228f2f862a95846c65a8518c79f48dfc8f188c/src/PubSubClient.h#L44
  switch (state)
  {
    case MQTT_CONNECTION_TIMEOUT:
      Serial.println(F("[TLC] mqtt connection timeout"));
      break;
    case MQTT_CONNECTION_LOST:
      Serial.println(F("[TLC] mqtt connection lost"));
      break;
    case MQTT_CONNECT_FAILED:
      Serial.println(F("[TLC] mqtt connect failed"));
      break;
    case MQTT_DISCONNECTED:
      Serial.println(F("[TLC] mqtt disconnected"));
      break;
    case MQTT_CONNECT_BAD_PROTOCOL:
      Serial.println(F("[TLC] mqtt bad protocol"));
      break;
    case MQTT_CONNECT_BAD_CLIENT_ID:
      Serial.println(F("[TLC] mqtt bad client id"));
      break;
    case MQTT_CONNECT_UNAVAILABLE:
      Serial.println(F("[TLC] mqtt unavailable"));
      break;
    case MQTT_CONNECT_BAD_CREDENTIALS:
      Serial.println(F("[TLC] mqtt bad credentials"));
      break;      
    case MQTT_CONNECT_UNAUTHORIZED:
      Serial.println(F("[TLC] mqtt unauthorised"));
      break;      
  }
}

void jsonConfig(JsonVariant json) // config payload
{

}

void jsonCommand(JsonVariant json) // do something payloads
{  


  if (json.containsKey("restart") && json["restart"].as<bool>())
  {
    ESP.restart();
  }
}


/*
 MQTT
 */
void initialiseMqtt(byte * mac)
{
  // Set the default client id to the last 3 bytes of the MAC address
  char clientId[32];
  sprintf_P(clientId, PSTR("%02x%02x%02x"), mac[3], mac[4], mac[5]);  
  mqtt.setClientId(clientId);
  
  // Register our callbacks
  mqtt.onConnected(mqttConnected);
  mqtt.onDisconnected(mqttDisconnected);
  mqtt.onConfig(jsonConfig);
  mqtt.onCommand(jsonCommand);  

  // Start listening for MQTT messages
  mqttClient.setCallback(mqttCallback);  
}


/*
 REST API
 */
void initialiseRestApi(void)
{
  // NOTE: this must be called *after* initialising MQTT since that sets
  //       the default client id, which has lower precendence than MQTT
  //       settings stored in file and loaded by the API

  // Set up the REST API
  api.begin();

  // Register our callbacks
  api.onAdopt(apiAdopt);

  server.begin();
}
#endif

void setup() {
#if defined(api_new)
  // Store the address of the stack at startup so we can determine
  // the stack size at runtime (see getStackSize())
  char stack;
  g_stack_start = &stack;

  // Set up serial
  initialiseSerial(); 

  // SPI.begin (SPI_SCK, SPI_MISO, SPI_MOSI);
  // SPI.begin (ETH_SCLK, ETH_MISO, ETH_MOSI);

  initialiseEthernet();

#endif
#if defined(api_old)
  Serial.begin(SERIAL_BAUD_RATE);
  delay(1000);
  Serial.println();
  Serial.println(F("\n==============================="));
  Serial.println(FW_NAME);
  Serial.print  (F("            v"));
  Serial.println(FW_VERSION);
  Serial.println(F("==============================="));

  pinMode(DISPLAY_CS_PIN, OUTPUT);
  digitalWrite(DISPLAY_CS_PIN, HIGH);

  // SPI.begin (SPI_SCK, SPI_MISO, SPI_MOSI);
  SPI.begin (ETH_SCLK, ETH_MISO, ETH_MOSI);

  // Set up ethernet and obtain an IP address
  byte mac[6];
  initialiseEthernet(mac);

  initialiseMqtt(mac);   // Set up MQTT (don't attempt to connect yet)

  initialiseRestApi();   // Set up the REST API
#endif

}

void loop() {
  // Check our MQTT broker connection is still ok
  mqtt.loop();
  
  Ethernet.maintain();

  EthernetClient client = server.available();
  #if defined(api_old)
  api.checkEthernet(&client);
  #endif
  #if defined(api_new)
  api.loop(&client);
  #endif

}

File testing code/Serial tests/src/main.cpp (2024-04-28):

#include <Arduino.h>
#include <ArduinoJson.h>

/*--------------------------- Version ------------------------------------*/
#define FW_NAME       "OXRS-AC-SERIAL_TEST-ESP32-FW"
#define FW_SHORT_NAME "SERIAL TEST"
#define FW_MAKER      "Austin's Creations"
#define FW_VERSION    "0.0.1"

// Serial
#define SERIAL_BAUD_RATE  115200
#define RS485_BAUD_RATE 9600
#define KNX_BAUD_RATE 9600

// stack size counter (for determine used heap size on ESP8266)
char * g_stack_start;

/*--------------------------- Instantiate Global Objects -----------------*/
// SoftwareSerial RS485Serial(RXPin, TXPin); // RX, TX
HardwareSerial &RS485 = Serial1;
HardwareSerial &KNX = Serial2;

/*--------------------------- Variables -----------------*/

// tracks the progress of messages back and forth to test all RX / TX modes
uint8_t messageStage = 0;

/*--------------------------- JSON builders -----------------*/

void initialiseSerial()
{
  Serial.begin(SERIAL_BAUD_RATE);
  RS485.begin(RS485_BAUD_RATE, SERIAL_8N1, RS485_RX, RS485_TX);
  KNX.begin(KNX_BAUD_RATE, SERIAL_8N1, KNX_RX, KNX_TX);
  delay(1000);
  Serial.println();
  Serial.println(F("\n==============================="));
  Serial.println(FW_NAME);
  Serial.print  (F("            v"));
  Serial.println(FW_VERSION);
  Serial.println(F("==============================="));

  #if(MODE)
    Serial.println(F("\n[MAIN ] starting up..."));
  #else
    Serial.println(F("\n[SEC ] starting up..."));
  #endif
  }

void transmitRS485Test()
{
  #if(MODE)
      delay(2500);
      digitalWrite(RS485_COMMUNICATION_CONTROL_PIN, RS485_TX_PIN_VALUE); // prepare to transmit
      StaticJsonDocument<200> doc1;
      doc1["message"] = "Hello RS485";
      serializeJson(doc1, RS485);
      delay(100);
      messageStage = 1;
  #else
    digitalWrite(RS485_COMMUNICATION_CONTROL_PIN, RS485_RX_PIN_VALUE); // Init receive
      if (RS485.available())
      {
        StaticJsonDocument<400> doc;
        DeserializationError err = deserializeJson(doc, RS485);
        if (err == DeserializationError::Ok)
        {
          // Print the values
          // (we must use as<T>() to resolve the ambiguity)
          Serial.print("\n json = ");
          serializeJson(doc, Serial);
          Serial.println("\n");
          delay(100);
          messageStage = 1;
        }
      }
  #endif
}

void recieveRS485Test()
{
  #if(MODE)
      digitalWrite(RS485_COMMUNICATION_CONTROL_PIN, RS485_RX_PIN_VALUE); // Init receive
      if (RS485.available())
      {
        StaticJsonDocument<400> doc;
        DeserializationError err = deserializeJson(doc, RS485);
        if (err == DeserializationError::Ok)
        {
          // Print the values
          // (we must use as<T>() to resolve the ambiguity)
          Serial.print("\n json = ");
          serializeJson(doc, Serial);
          Serial.println("\n");
          delay(100);
          messageStage = 2;
        }
      }
  #else
      delay(2500);
      digitalWrite(RS485_COMMUNICATION_CONTROL_PIN, RS485_TX_PIN_VALUE); // prepare to transmit
      StaticJsonDocument<200> doc1;
      doc1["message"] = "Bye RS485";
      serializeJson(doc1, RS485);
      delay(100);
      messageStage = 2;
  #endif
}

void transmitKnxTest()
{
  #if(MODE)
      delay(2500);
      StaticJsonDocument<200> doc1;
      doc1["message"] = "Hello KNX";
      serializeJson(doc1, KNX);
      Serial.println("KNX sent");
      delay(100);
      messageStage = 3;
  #else
      if (KNX.available())
      {
        Serial.println("KNX recieve");
        StaticJsonDocument<400> doc;
        DeserializationError err = deserializeJson(doc, KNX);
        if (err == DeserializationError::Ok)
        {
          // Print the values
          // (we must use as<T>() to resolve the ambiguity)
          Serial.print("\n json = ");
          serializeJson(doc, Serial);
          Serial.println("\n");
          delay(100);
          messageStage = 3;
        }
      }
  #endif
}

void recieveKnxTest()
{
  #if(MODE)
      if (KNX.available())
      {
        StaticJsonDocument<400> doc;
        DeserializationError err = deserializeJson(doc, KNX);
        if (err == DeserializationError::Ok)
        {
          // Print the values
          // (we must use as<T>() to resolve the ambiguity)
          Serial.print("\n json = ");
          serializeJson(doc, Serial);
          Serial.println("\n");
          delay(100);
          messageStage = 5;
        }
      }
  #else
      delay(2500);
      StaticJsonDocument<200> doc1;
      doc1["message"] = "Bye KNX";
      serializeJson(doc1, KNX);
      delay(100);
      messageStage = 5;
  #endif
}


void setup() {

  initialiseSerial();

  pinMode(RS485_COMMUNICATION_CONTROL_PIN, OUTPUT);
  digitalWrite(RS485_COMMUNICATION_CONTROL_PIN, RS485_RX_PIN_VALUE);

}

void loop() {

  if(messageStage == 0)
  {
    transmitRS485Test();
  }
  if(messageStage == 1)
  {
    recieveRS485Test();
  }
  if(messageStage == 2)
  {
    transmitKnxTest();
  }
  if(messageStage == 3)
  {
    recieveKnxTest();
  }

  
}

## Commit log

2024-08-09 update adapter to rev 002
    [BOM-knx adapter.csv, knx adapter.kicad_pcb, knx adapter.kicad_sch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]
2024-08-09 newest and tested version of oxrs black
    [BOM-oxrs black 004.csv, oxrs black 004.kicad_pcb, oxrs black 004.kicad_sch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]
2024-08-15 incorrect part number for qwiic was used
    [BOM-oxrs black 004.csv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]
